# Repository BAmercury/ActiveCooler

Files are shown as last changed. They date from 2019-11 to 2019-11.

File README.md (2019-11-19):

# ActiveCooler

Program that configures MCU's timer registers to sample sensor data and output PWM to an HVAC cooling fan

## Hardware
Device: SparkFun Pro Micro 5V/16MHz (Atmega32U4)

Temperature Sensor: DS18B20

Fan: SanAce 92W XF-P05801, DC 24V/1.0A

- https://www.mouser.com/datasheet/2/471/San_Ace_92WL38_E-1316567.pdf

Voltage Regulator: TRACO THD 12-4812WI, DC 18-75V In, 12V/1000ma Out

- https://www.mouser.com/ProductDetail/TRACO-Power/THD-12-4812WI?qs=ckJk83FOD0X7VPMTWOOrrA%3D%3D 

## Libraries used:
https://github.com/milesburton/Arduino-Temperature-Control-Library

https://github.com/PaulStoffregen/OneWire

## Notes
1. Make sure your Arduino IDE is setup for uploading code to the SparkFun Pro Micro Board:

    - https://learn.sparkfun.com/tutorials/pro-micro--fio-v3-hookup-guide/all

    - https://cdn.sparkfun.com/datasheets/Dev/Arduino/Boards/ProMicro16MHzv1.pdf

2. The code simply uses the linear mapping function map() to map temperatures to motor speeds
    
    - Motor speeds range from 0-100% duty cycle (0-100)

    - Exposed parameters are defined at the top of the code

        - MOTOR_MIN, MOTOR_MAX

        - TEMP_MIN, TEMP_MAX

3. Error Catching (In both cases, fan is turned off):

    - When sensor's sense wire is disconnected from MCU

    - When sensor itself is disconnected from ground and power

4. Exposed a parameter (SAMPLING_PERIOD) for changing sensor update rate (In miliseconds)

## Wiring Schematic:
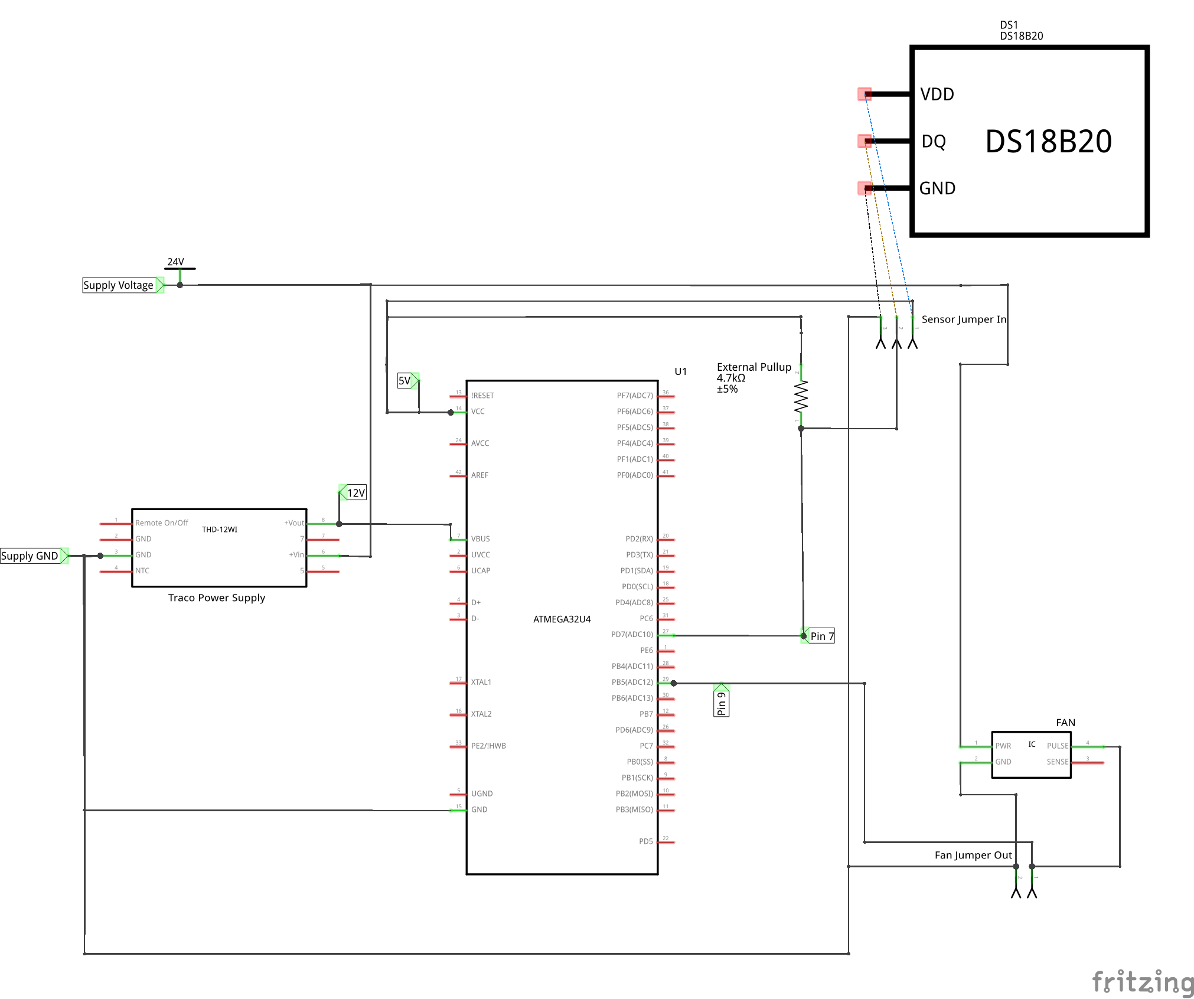
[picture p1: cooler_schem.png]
Wiring Guide


## Perf-Board Assembly:
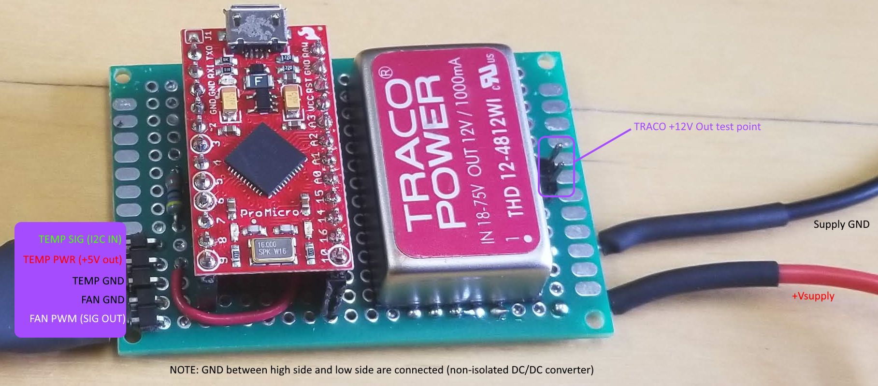
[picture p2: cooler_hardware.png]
Annotated perfboard assembly


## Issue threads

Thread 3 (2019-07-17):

Spec out voltage regulator

BAmercury, 2019-07-17:
Links to various regulators

BAmercury, 2019-07-17:
https://www.mouser.com/ProductDetail/TRACO-Power/THD-12-4812WI?qs=ckJk83FOD0X7VPMTWOOrrA%3D%3D

BAmercury, 2019-07-17:
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

Sparkfun's onboard voltage regulator max is 18 v

BAmercury, 2019-07-17:
https://cdn-shop.adafruit.com/product-files/3081/mic5219.pdf

BAmercury, 2019-07-17:
https://assets.tracopower.com/20190716164234/THD12WI/documents/thd12wi-application.pdf

BAmercury, 2019-07-17:
https://www.mouser.com/datasheet/2/687/tmr6wi-519339.pdf

BAmercury, 2019-07-17:
Going with the THD 12-4812WI

BAmercury, 2019-07-17:
Wire size calculator:
https://www.wirebarn.com/Wire-Calculator-_ep_41.html

BAmercury, 2019-11-05:
**https://linuxpropaganda.wordpress.com/2018/07/08/install-fritzing-in-xubuntu-18-04/**

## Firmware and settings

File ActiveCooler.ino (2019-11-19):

/* 
    Simple Active Cooler
    Bhautik (Brian) Amin
    brianamin@dpiuav.com

    Device: SparkFun Pro Micro 5V/16MHz (Atmega32U4)
    Temperature Sensor: DS18B20
    Fan: SanAce 92W XF-P05801, DC 24V/1.0A
*/
#include <DallasTemperature.h>
#include <OneWire.h>

// Pins
#define PIN_TEMP_ONEWIRE 7
#define PIN_MOTOR_OUTPUT 9
#define PIN_DEBUG 2

// Temperature Ranges (fahrenheit)
#define TEMP_MIN 80
#define TEMP_MAX 105
// Motor Speed Ranges
#define MOTOR_MIN 20 // (In terms of duty cycle) At TEMP_MIN this speed will engage
#define MOTOR_MAX 100 // (In terms of duty cycle) At TEMP_MAX this speed will engage

#define PWM_TOP 639 // TOP Value for PWM

unsigned long SAMPLING_PERIOD = 30; // Period in milliseconds
unsigned long previous_ms = 0; 

// Configure onewire object
OneWire oneWire(PIN_TEMP_ONEWIRE);

// Pass onewire object reference to Temperature library
DallasTemperature sensors(&oneWire);

long pwm = 0;

// Convert given duty cycle to valid pwm value
long DUTY2PWM(int duty)
{
    if (duty == 100)
    {
        return PWM_TOP;
    }
    else
    {
        long pwm = ( (PWM_TOP * duty) / 100);
        return pwm;
    }

}

void setup(void)
{
    Serial.begin(115200);
    // Start the temperature library
    sensors.begin();
    pinMode(PIN_MOTOR_OUTPUT, OUTPUT);
    pinMode(PIN_DEBUG, OUTPUT);
    // Using Timer 1 for PWM (OC1A, PB5, Pin 9 on Sparkfun Board)
    // Set Timer 1 for 25kHz frequency
    // 25kHz = (16 Mhz / PRESCALER) / (TOP + 1)
    // Prescaler = 1, TOP = 639
    TCCR1A = (_BV(COM1A1) |_BV(WGM11) ); // Noninverting PWM signal
    TCCR1B = (_BV(WGM13) | _BV(WGM12) | _BV(CS10) ); // Prescaler 1
    TCCR1C = 0;
    ICR1 = PWM_TOP; // TOP value
    DDRB |= _BV(DDB5); // Enable output




}

void loop(void)
{

    // Check for set sampling time interval
    unsigned long current_ms = millis();
    if ((unsigned long)(current_ms - previous_ms) >= SAMPLING_PERIOD)
    {

        /*
            sensors.requestTemperatures() issues a global command
            to all connected sensors on the bus
        */ 
        digitalWrite(PIN_DEBUG, HIGH); // Set Debug pin how, use scope to measure sensor update rate
        sensors.requestTemperatures();
        float temperature = sensors.getTempFByIndex(0);

        // Refer to DallasTemperature.h for error codes
        // If equal to negative -196.6 yield an error
        // If the sensor wire is disconnected or if sensor is removed from ground
        if (temperature != DEVICE_DISCONNECTED_F)
        {
            Serial.print("Temperatuare (F): ");
            Serial.print(temperature);
            Serial.print(", ");
            // Map the temperature to fan pwm value
            pwm = map((long)temperature, TEMP_MIN, TEMP_MAX, DUTY2PWM(MOTOR_MIN), DUTY2PWM(MOTOR_MAX));
            Serial.print("PWM: ");
            // Apply limits (Between 0 and 639)
            if (pwm > PWM_TOP)
            {
                pwm = PWM_TOP;
            }
            else if (pwm < 0)
            {
                pwm = 0;
            }
            Serial.println(pwm);
        }
        else
        {
            Serial.println("ERROR");
            pwm = 0;
        }
        previous_ms = millis();
        digitalWrite(PIN_DEBUG, LOW);
    }

    // Pin 9 on Sparkfun Pro Micro is connected to Timer 1
    OCR1A = pwm; // Set PWM
}

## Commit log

2019-07-09 Just need to finish documentation
    Quick script to change fan speed based on temperature reading following linear curve. PWM frequency set to 25KHz
2019-07-09 added configuration for motor speeds
2019-07-10 Fixed units to F, added readme
    [cooler.fzz]
2019-07-10 Fixed some print features and gave it a small test
    [ActiveCooler.ino]
2019-07-10 Going to branch
    Branching to experiment with ISR/timers to sample temperature sensor
    [cooler.fzz]
2019-07-11 Added comments, branching to try different timer/clock setup
2019-07-11 Setup timer 1 just need to test
    Set the registers for timer 1 to 25khz pwm going to test with fan
2019-07-11 Fixed some syntax and register parameters, 25khz pwm achieved
    Need to test with hardware
    [ActiveCooler.ino]
2019-07-11 fixed problem with mapping duty cycle to pwm,
    need to do some more error catching regarding sensor pertubations
    [ActiveCooler.ino]
2019-07-11 Cleaned up code and verified
    Only error I wasn't able to catch would be when sensor disconnected from power
    [ActiveCooler.ino]
2019-07-11 Updated schematic for new pinout
    [cooler.fzz]
2019-07-12 Added in Timer3 doing an interrupt routine to sample temperature sensor at a desired rate, need to test
2019-07-12 Updated some documentation
    Need to switch branches again and test update rate for sensor
2019-07-12 added control in for update rate
    But now error catching does not work as well
    [ActiveCooler.ino]
2019-07-12 Using Timer0 to add in update rate control
    Should help smooth out motor pwm update
2019-07-17 Added fan datasheet
2019-11-05 Updated wiring schematic
    [cooler.fzz]
2019-11-05 Fixed schematic
    [cooler.fzz]
2019-11-05 Schematic version issue
    [cooler.fzz]
2019-11-05 Still figuring out version issue
    [cooler.fzz]
2019-11-19 Updated temp min value
    [cooler.fzz]
2019-11-19 Bug fix regarding integer math
    [ActiveCooler.ino]
2019-11-19 Updating documentation
    [cooler.fzz]
2019-11-19 Updated documentation and bug fix for code (where pwm output negative)
    [ActiveCooler.ino]
